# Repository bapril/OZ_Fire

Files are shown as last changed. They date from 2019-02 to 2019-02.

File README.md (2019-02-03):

# OZ_FIRE
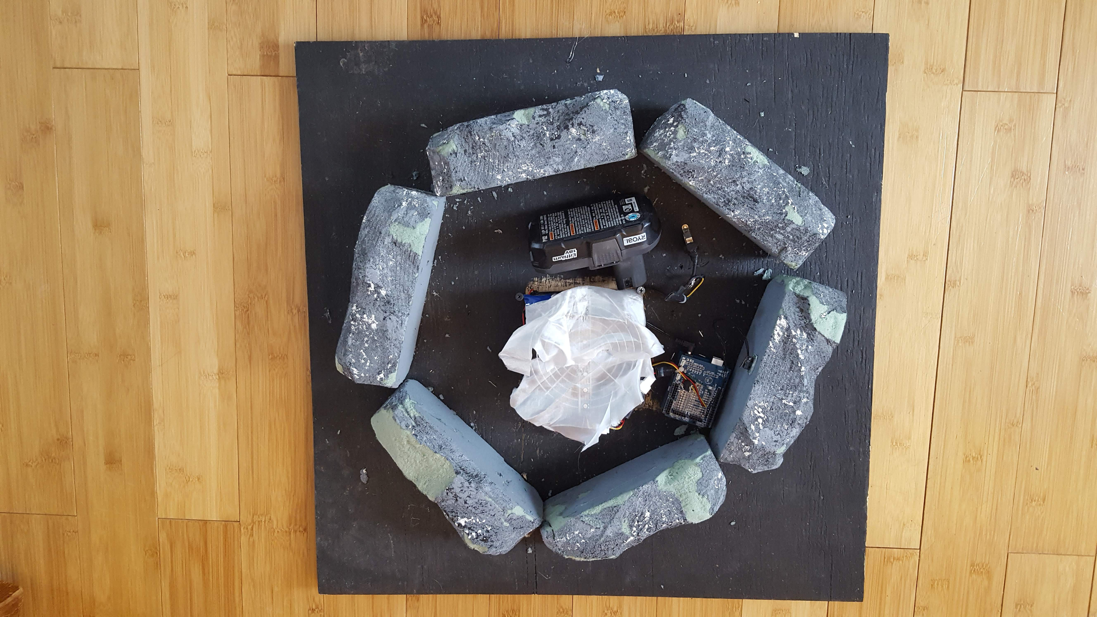
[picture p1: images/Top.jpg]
Image of top

## Overview

This is a simple self-contained Arduino powered prop campfire for theatrical use.

## Acknowledgements
* Adafruit for the NeoPixel library.

## Operation

Connecting the battery should power on the Arduino only. The power LED on the UNO should be lit. Pressing the button once will move the unit into ramp-up mode where the power LED activity and brightness as well as the fan speed will grow until full power is reached. At full power the logic automatically moves into the run mode. Pushing the button again will move to the ramp-down mode moving towards power off. The time this takes can be adjusted in code. Pressing the button during the ramp-down will go to instant off.

The debounce code on the button is written for a theatrical setting. Pressing and holding the button will trigger one state change. (no matter how long you hold the button). The button could be placed so it can be actuated by foot, or by a "poker" in the fire. 

## Construction
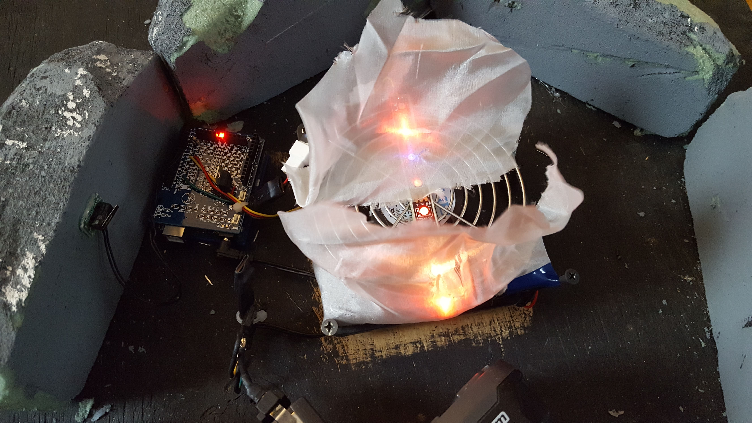
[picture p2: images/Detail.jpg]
Image of Detail

### Materials
* 2x2' piece of 3/4" Plywood as a base. (painted black)
* Foam to build the rocks.
* wood/sticks depending on the type/size fire you want.
* Arduino UNO Rev3
* Arduino proto-shield for easy wiring.
* 1 4" PC fan
* 4 2-3" Drywall screws to mount the fan above the plywood.
* Strip of 8 RGBW neopixels
* Battery (18V Ryobi)
* Battery clip
* Bridge Rectifier (or 4 diodes)
* 7812 12V voltage rectifier.
* N-channel MOSFET
* Optional 7805 rectifier to take some load off of the Uno

### Circuit
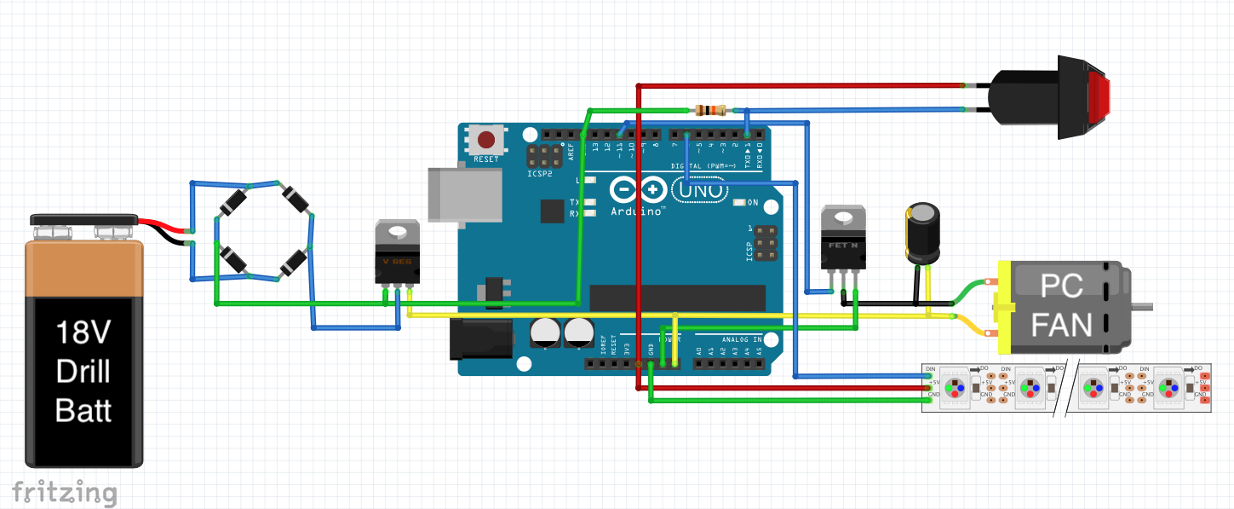
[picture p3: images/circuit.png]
Image of circuit


Key elements: (Left to Right, then Top Down)
* Battery, I use a 18V Ryobi +ONE battery, connected by a clip freed from an old drill.
* Bridge rectifier, prevents clipping the batter on backwards from becoming a problem.
* 7812 rectifier, to turn the ~18V into 12V that the Arduino can take in (I use a barrel-jack).
* Arduino Uno Rev3.
* Button and pull-down resistor. (Pin 2).
* N-channel MOSFET feeding a large PC fan with a cap. to take the whine out of the PWM.
* A strip of (8) RGBW Neopixels tied to Pin 6

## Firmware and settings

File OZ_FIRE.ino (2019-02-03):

#include <Adafruit_NeoPixel.h>

#define COLOR_COUNT 10
#define LED_PIN 6
#define FAN_PIN 11
#define NUMPIXELS 8
#define BUTTON_PIN 2

//FSM states
#define S_OFF 0
#define S_FADE_UP 1
#define S_RUN 2
#define S_FADE_OUT 3

//Button states
#define BTN_UP 0
#define BTN_DOWN 1

Adafruit_NeoPixel pixels = Adafruit_NeoPixel(NUMPIXELS, LED_PIN, NEO_GRBW + NEO_KHZ800);

uint32_t colors[] = {
  pixels.Color(200, 20, 0, 0),
  pixels.Color(200, 10, 0, 0),
  pixels.Color(200, 0, 0, 0),
  pixels.Color(155, 5, 0, 0),
  pixels.Color(155, 0, 0, 0),
  pixels.Color(100, 0, 0, 0),
  pixels.Color(50, 0, 0, 0),
  pixels.Color(25, 0, 0, 0),
  pixels.Color(0, 0, 4, 0), //Blue
  pixels.Color(5, 0, 0, 0),
  pixels.Color(80, 30, 0, 0),
  pixels.Color(150, 15, 0, 7),
  pixels.Color(100, 20, 0, 10),
  pixels.Color(0, 0, 0, 25),
  pixels.Color(0, 0, 0, 0),
};

uint8_t current_colors[] = {0, 0, 0, 0, 0, 0, 0, 0};
uint8_t *current_color = current_colors;
uint8_t out_state = 0;
uint8_t max_led_level = 255;
uint8_t led_level = 0;
uint8_t led_var = 255;
uint8_t max_fan_level = 255;
uint8_t fan_level = 0;
uint8_t fan_var = 12;
uint8_t fan_min = 64;
uint8_t step_delay = 2;

long debounce_timer = 0;
long debounce_time = 50; //50 ms.
bool button_pressed = false;
int last_button_state;
int button_state;
bool need_up_debounce = true;

byte state;

void setup() {
  state = S_OFF;
  //Need some good random.
  randomSeed(analogRead(0));

  pixels.begin(); // This initializes the NeoPixel library.
  // now we turn off the neopixels
  for (int i = 0; i < NUMPIXELS; i++) {
    pixels.setPixelColor(i, 0,0,0,0); // Off
  }

  pixels.show(); // This sends the updated pixel color to the hardware.
  pinMode(FAN_PIN,OUTPUT);
}

void loop() {
  //debounce the Button. 
  if (digitalRead(BUTTON_PIN)){
    button_state = BTN_DOWN;
  } else {
    button_state = BTN_UP;
  }

  if (button_state != last_button_state){
    debounce_timer = millis(); //reset timer
  } else {
    if(millis() - debounce_timer > debounce_time){
      if(button_state == BTN_DOWN & need_up_debounce == false){
        button_pressed = true;
        need_up_debounce = true;
      } else if (button_state == BTN_UP){
        need_up_debounce = false;
      }
    }
  }
  last_button_state = button_state;

  //Manage update of state
  if(state == S_OFF){
    if (button_pressed){
      state = S_FADE_UP;
      button_pressed = false;
    }
    fan_level = fan_min -1;
    led_level = 0;
  } else if (state == S_FADE_UP) {
    if (button_pressed){
      state = S_RUN;
      button_pressed = false;
    }
    if (led_level < max_led_level) led_level++;
    if (fan_level < max_fan_level) fan_level++;
    if (fan_level >= max_fan_level & led_level >= max_led_level) state = S_RUN;
    delay(step_delay);
  } else if (state == S_RUN) {
    if (button_pressed){
      state = S_FADE_OUT;
      button_pressed = false;
    }
  } else if (state == S_FADE_OUT) {
    if (button_pressed){
      state = S_OFF;
      button_pressed = false;
    }
    if(led_level > 0) led_level--;
    if(fan_level >= fan_min) fan_level--;
    if(fan_level <= fan_min) fan_level = 0;
    if(fan_level == 0 & led_level == 0) state = S_OFF;
  }
  //Update effects
  fanUpdate(fan_level);
  flameGen(colors, current_color , COLOR_COUNT, led_level, led_var);
  delay(100);
}

void fanUpdate( uint8_t level){
  if(level < fan_min){
     analogWrite(FAN_PIN,0);
  } else if (level < fan_min + fan_var) {
    analogWrite(FAN_PIN, level);
  } else {
    analogWrite(FAN_PIN, level - rand(fan_var));
  }
}

void flameGen(uint32_t colors[COLOR_COUNT], uint8_t current_color[NUMPIXELS], uint8_t color_count, uint8_t Bright, uint8_t led_var) {
  int update_count = (int)random(led_var & 7);
  for (int i = 0; i < update_count; i++) {
    int led = random(NUMPIXELS) ;
    pixels.setPixelColor(led, colors[(int)random(led_var & 15)]);
  }
  pixels.setBrightness(Bright);
  pixels.show();
}

int genNewColor(int color, uint8_t led_var) {
  int distance = (int)random(led_var);
  color += distance;
  if (color > COLOR_COUNT) {
    color = 0;
  }
  return color;
}
